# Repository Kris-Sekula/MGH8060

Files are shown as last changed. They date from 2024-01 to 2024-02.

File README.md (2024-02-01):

# MGH8060
SC/MP INS8060-based microcomputer running National Industrial Basic Language (NIBL)

Here is an overview of the device:

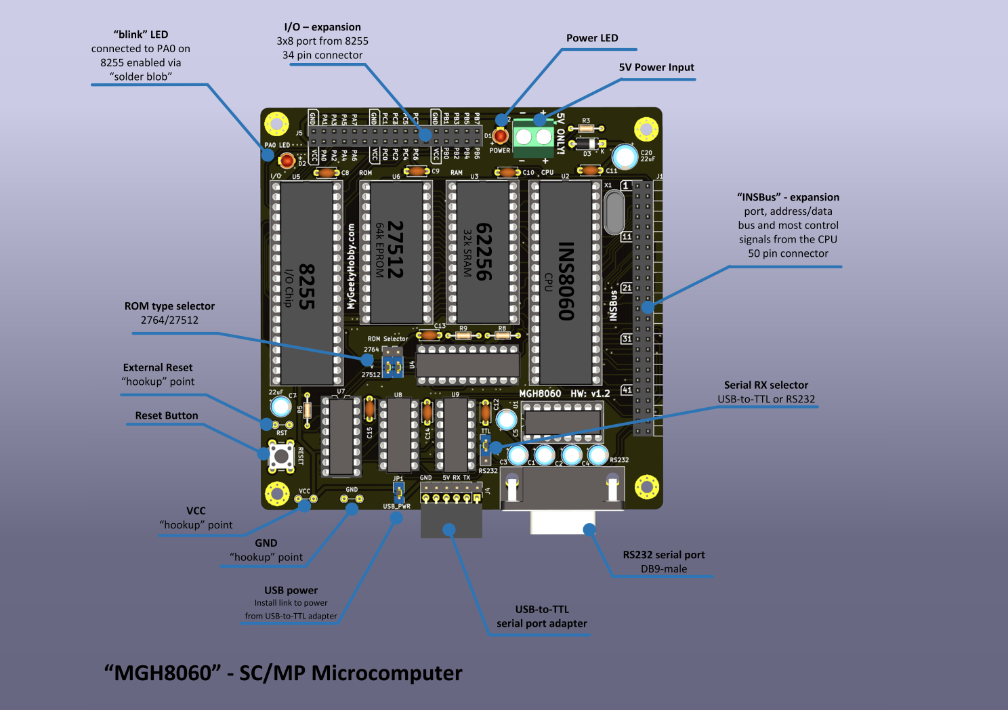
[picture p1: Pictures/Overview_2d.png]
MGH8060_overview


And here is my assembled unit - hardware v1.2

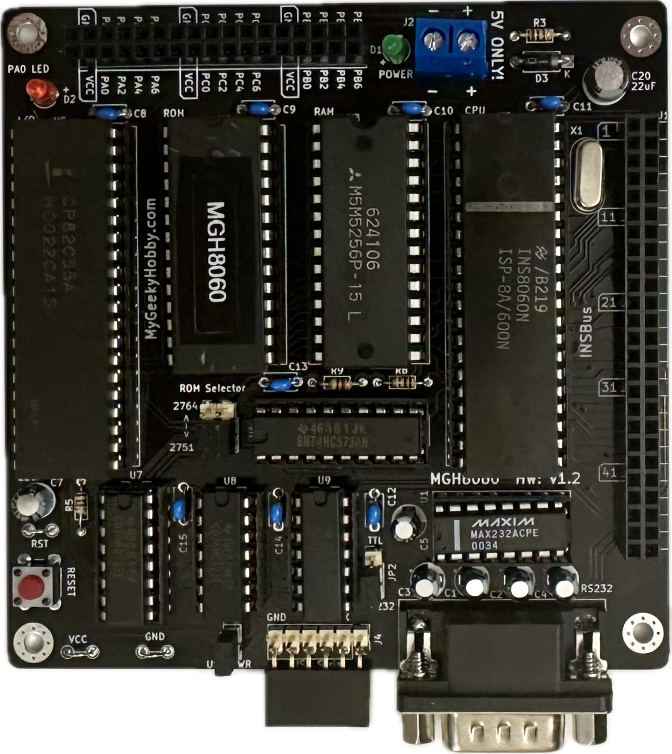
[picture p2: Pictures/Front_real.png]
Assembled_unit_v1.2


## Bill of Materials

| Component type | Reference | Description | Quantity |
| --- | --- | --- | --- |
| PCB | | [Order from PCBWay](https://www.pcbway.com/project/shareproject/MGH8060_SC_MP_Microcomputer_731c2144.html)| 1 |
| Integrated Circuit | U1 | MAX232(A) - RS232 Driver, 16 pin DIP | 1 | 
| Integrated Circuit | U2 | INS8060 - SC/MP II Microcontroller, 40 pin DIP | 1 |
| Integrated Circuit | U3 | HM62256B - 32kb SRAM, 28 pin DIP | 1 |
| Integrated Circuit | U4 | 74LS573 - high-speed octal latch, 20 pin DIP | 1 |
| Integrated Circuit | U5 | 8255A - Programmable Peripheral Interface, 40 pin DIP | 1 |
| Integrated Circuit | U6 | 27C512 - 64kb EPROM, 28 pin DIP | 1 |
| Integrated Circuit | U7 | 74LS138 - 3-to-8 line decoder, 16 pin DIP | 1 |
| Integrated Circuit | U8 | 74LS21 - Dual 4 -Input AND Logic, 14 pin DIP | 1 |
| Integrated Circuit | U8 | 74LS04 - HEX Inverter, 14 pin DIP | 1 |
| LED | D1 | LED indicator, 3 mm | 1 |
| LED | D2 | LED indicator, 3 mm | 1 |
| Diode | D3 | 1N4002,  general-purpose diode | 1 |
| Pin Header | J1 | 2x17 header female, 2.54 mm pitch | 1 |
| Connector | J2 | Screw terminal | 1 |
| Connector | J3 | DB9 male | 1 |
| Pin Header | J4 | 1x6 pin header, 2.54 mm pitch, angle | 1 |
| Pin Header | J5 | 2x25 header female, 2.54 mm pitch | 1 |
| Pin Header | J6 | 1x6 pin header, 2.54 mm pitch | 1 |
| Pin Header | JP1 | 1x2 pin header, 2.54 mm pitch | 1 |
| Pin Header | JP2-JP4 | 1x3 pin header, 2.54 mm pitch | 3 |
| Capacitor | C8-C15 | 1 uF, 16V, electrolytic, 2.54 mm pitch | 5 |
| Capacitor | C6 | 27pF, ceramic, 2.54 mm pitch | 1 |
| Capacitor | C8-C15 | 0.1 uF, 50V, MLCC, 5 mm pitch | 8 |
| Capacitor | C7,C20 | 22uF, 6.8V, electrolytic, 2.54 mm pitch | 2 |
| Resistor | R1 | 160 kohm, 0.125 W, axial | 1 |
| Resistor | R2-R4,R8 | 1 kohm, 0.125 W, axial | 4 |
| Resistor | R5 | 10k kohm, 0.125 W, axial | 1 |
| Resistor | R9 | 4.7k kohm, 0.125 W, axial | 1 |
| Crystal | X1 | 4MHz, short 3.5mm heigh max | 1 |
| IC Socket | U8,U9 | 14 pin DIP | 2 |
| IC Socket | U1,U7 | 16 pin DIP | 2 |
| IC Socket | U4 | 20 pin DIP | 1 |
| IC Socket | U3,U6 | 28 pin DIP | 2 |
| IC Socket | U2,U5 | 40 pin DIP | 2 |

## Memory Map

| Start | End | RAM | ROM | I/O |
| :---: | :---: | :----: | :----: | :----: |
| 0x0000 | 0x1FFF |  | X |  |			
| 0x2000 | 0x3FFF | X |  |  |			
| 0x4000 | 0x5FFF | X |  |  |			
| 0x6000 | 0x7FFF | X |  |  |			
| 0x8000 | 0x9FFF |  | X |  |			
| 0xA000 | 0xBFFF |  |  | X |			
| 0xC000 | 0xDFFF |  | X |  |			
| 0xE000 | 0xFFFF |  | X |  |

| Address | 8255 Function |
| :---: | :---: |
| 0xA000 | Port A |
| 0xA001 | Port B |
| 0xA002 | Port C |
| 0xA003 | Ctrl Register |

### Schematic
[Schematic - Version 1.2](Hardware/mgh8060_v1.2.pdf)

### Credits
* The device is based on the work of [Ronald Dekker](https://www.dos4ever.com/SCMP/SCMP.html#circuit)

* Early versions of my design were reviewed by Phil(aka [Retro Phil](https://www.mccrash-racing.co.uk/philg/picl/picl.htm)) who offered a lot of helpful suggestions, he also contributed all the firmware for MGH8060

## Release Notes

I used HCT parts for most of the ICs. Power usage was about 60mA

I used Winbond W27C512 (EEPROM pin compatible with EPROMs)

Please consider getting the PCB from my sponsor PCBWay

PCBWay (https://www.pcbway.com/project/shareproject/MGH8060_SC_MP_Microcomputer_731c2144.html)

If you found this helpful and you like the work I do, why not buy me a coffee, thanks! :)



### Changes
* Version 1.2:
  
  * Fixed missing connections. 

* Version 1.1:
  
  * Corrected CE signals (thanks Phil)

* Version 1.0
  
  * Initial version

## License

Copyright 2024 Kris Sekula

This work is licensed under a [Creative Commons Attribution-NonCommercial 4.0 International (CC BY-NC 4.0) ](https://creativecommons.org/licenses/by-nc/4.0/).

### Trademarks

* Other names and brands may be claimed as the property of others.

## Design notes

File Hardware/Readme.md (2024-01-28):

In the KiCad folder, you can find the KiCad sources for the PCB v1.2. 

## __Before you download the files, please consider ordering the PCBs from *PCBWay* by following this [-> link <-](https://www.pcbway.com/project/shareproject/MGH8060_SC_MP_Microcomputer_731c2144.html).__

I get a small portion of your order that I can use towards my future open-source projects, and more importantly, PCBWay will be more likely to sponsor me again.

Thanks again to PCBWay for sponsoring the PCBs used in this project.

PCBWay (https://www.pcbway.com/project/shareproject/MGH8060_SC_MP_Microcomputer_731c2144.html)

If you found this helpful and you like the work I do, why not buy me a coffee, thanks! :)



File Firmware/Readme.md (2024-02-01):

The main firmware file (mgh8060v2.hex) consists of 3 projects:

* National Industrial Basic Language (NIBL)
* NIBL with floating point extension
* Kitbug+ monitor

Connect to the device using one of the serial ports (RS232 or USB-to-TTL adapter), you should be using 2400 baud, 8-bit data, no parity, and one stop bit. The SC/MP is not fast enough to process at 2400 so you need to add a delay between characters and at the end of the line, here are my settings for the popular Tera Term program on Windows:

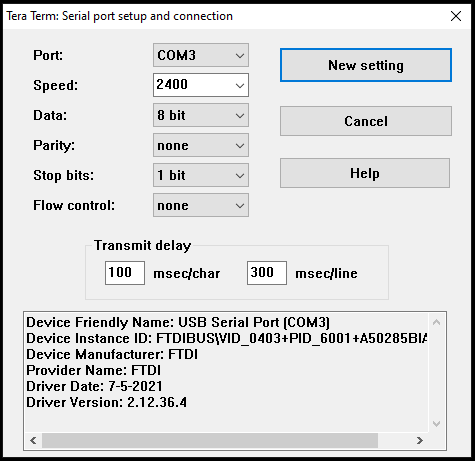
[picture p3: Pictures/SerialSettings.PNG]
SerialSettings


You may also want to adjust the "Terminal settings":

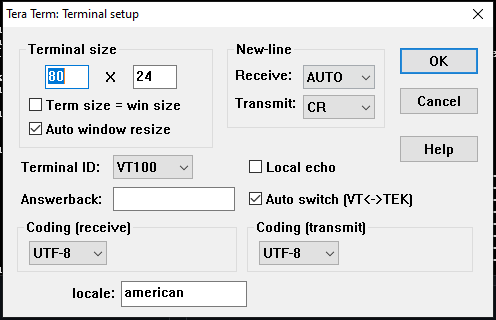
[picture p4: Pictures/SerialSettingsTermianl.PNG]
SerialSettingsTerminal


When you reset the board, a menu will be presented, select by pressing 1, 2 or 3:

Menu

There are also a few demo programs that can be uploaded via Kitbug+ "S" command and executed with the "G" command (filename indicates the upload and execution address)
| Filename | Description |
| :--: | :--: |
|fade_led_x6400.bin ||
|flash_led_x6000.bin ||
|life_x6800_jc.bin ||
|scmp_sine_0x6800.bin ||
|scmp_xmas2023_0x2800.bin ||
|xmasstar_x4800.bin ||

## Big thanks to "Retro Phil" who has been maintaining the Kitbug+ firmware and adapted it to the new memory mapping on this PCB, he has also created the "selection menu" for MGH8060... you can follow his adventures with SC/MP on his [page](https://www.mccrash-racing.co.uk/philg/picl/picl.htm).

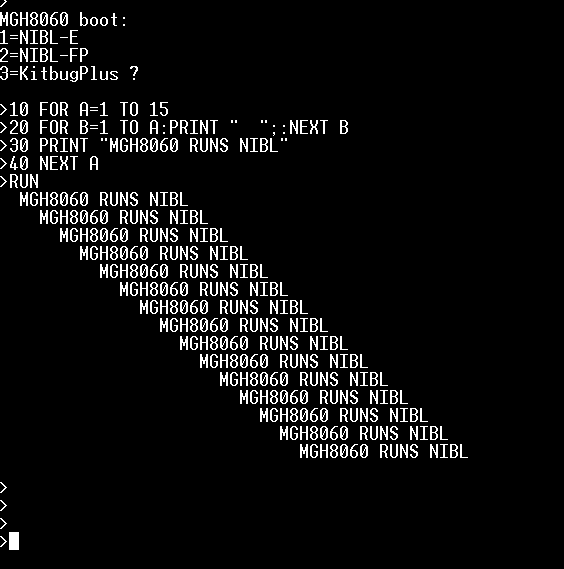
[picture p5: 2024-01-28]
Pictures/BOOTED.PNG

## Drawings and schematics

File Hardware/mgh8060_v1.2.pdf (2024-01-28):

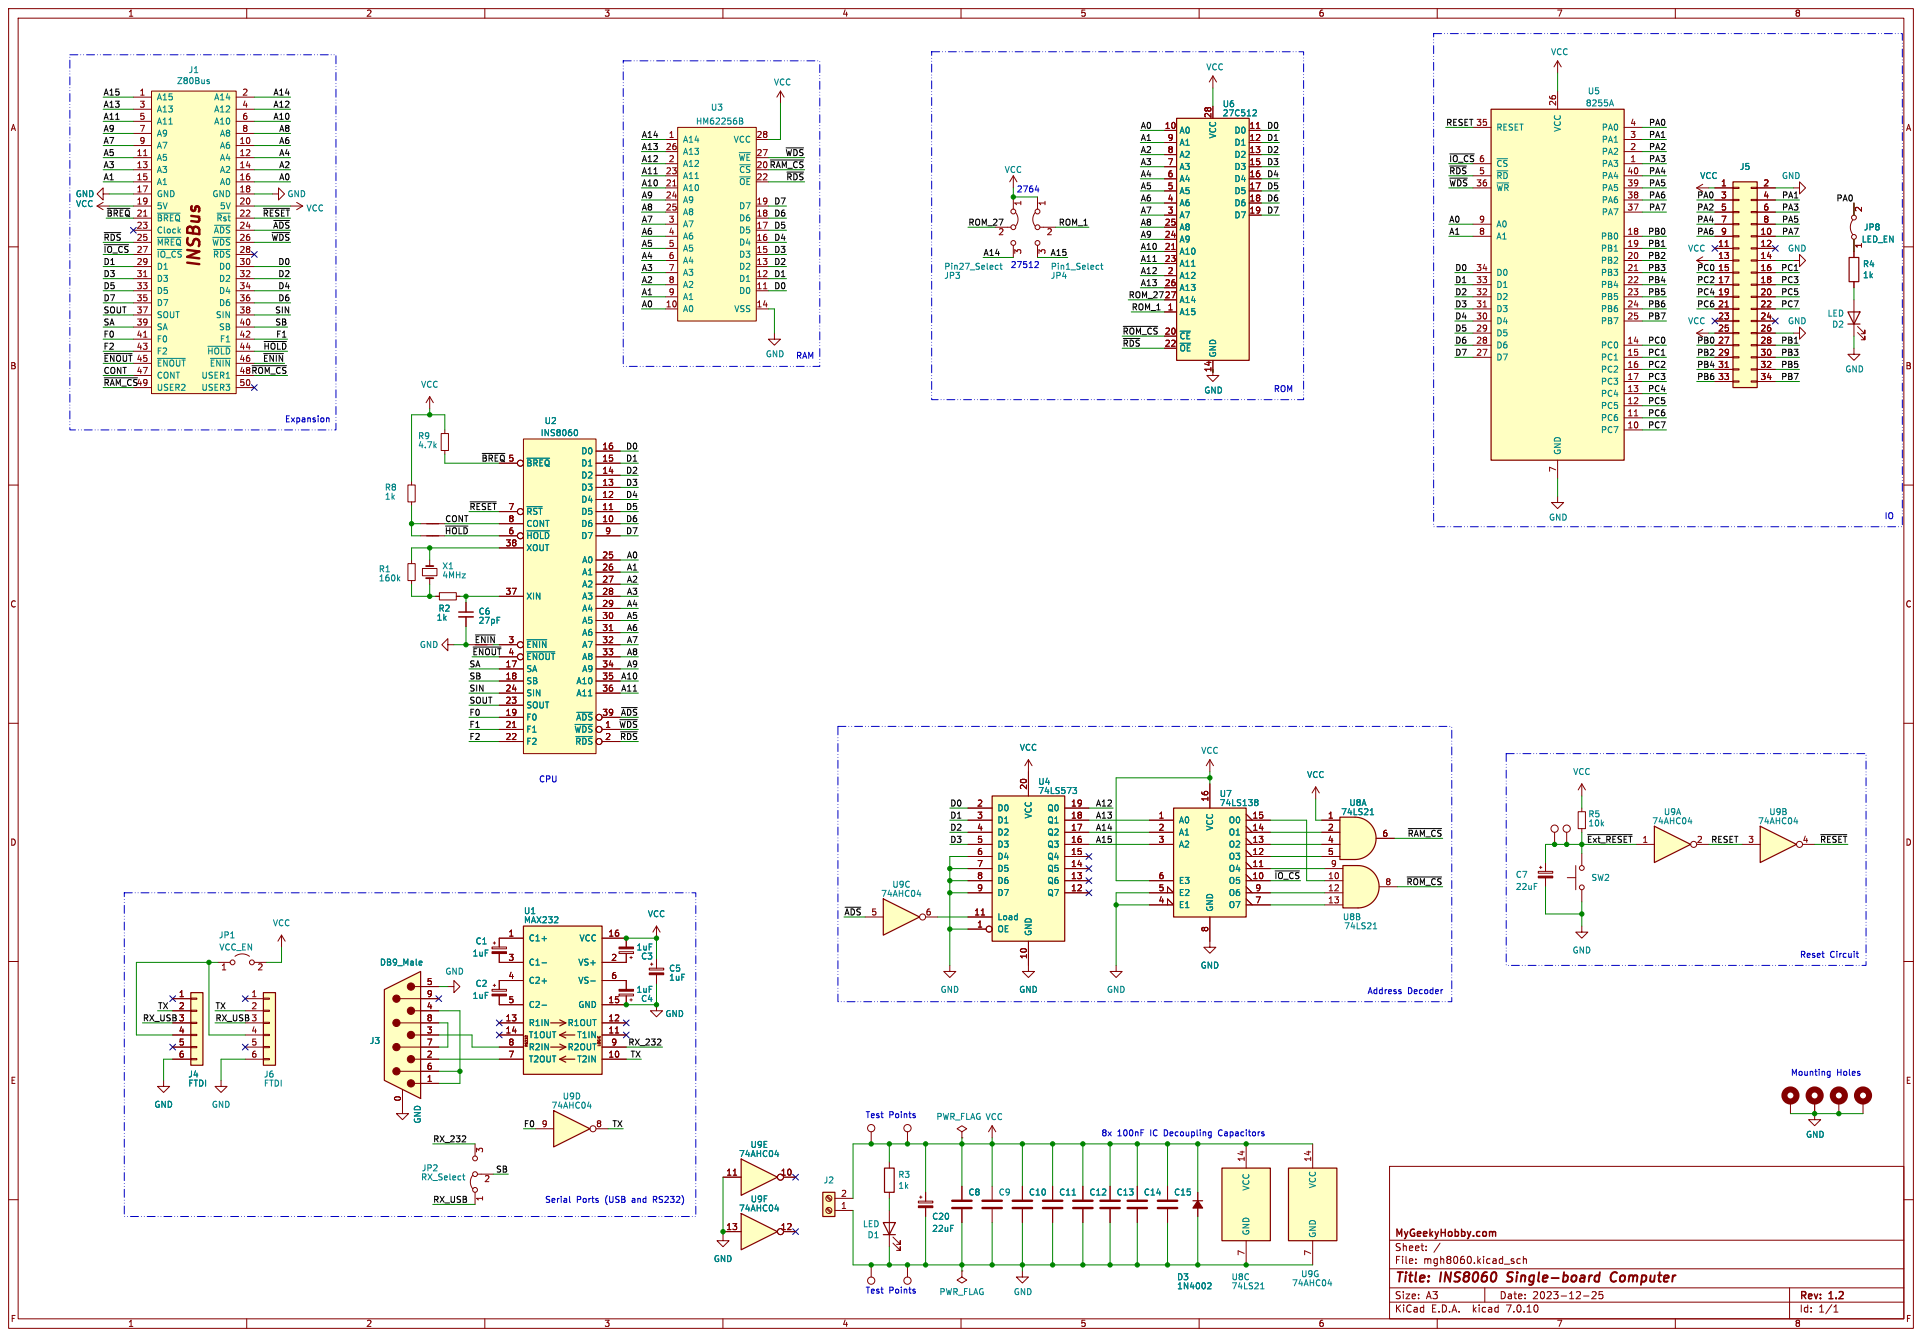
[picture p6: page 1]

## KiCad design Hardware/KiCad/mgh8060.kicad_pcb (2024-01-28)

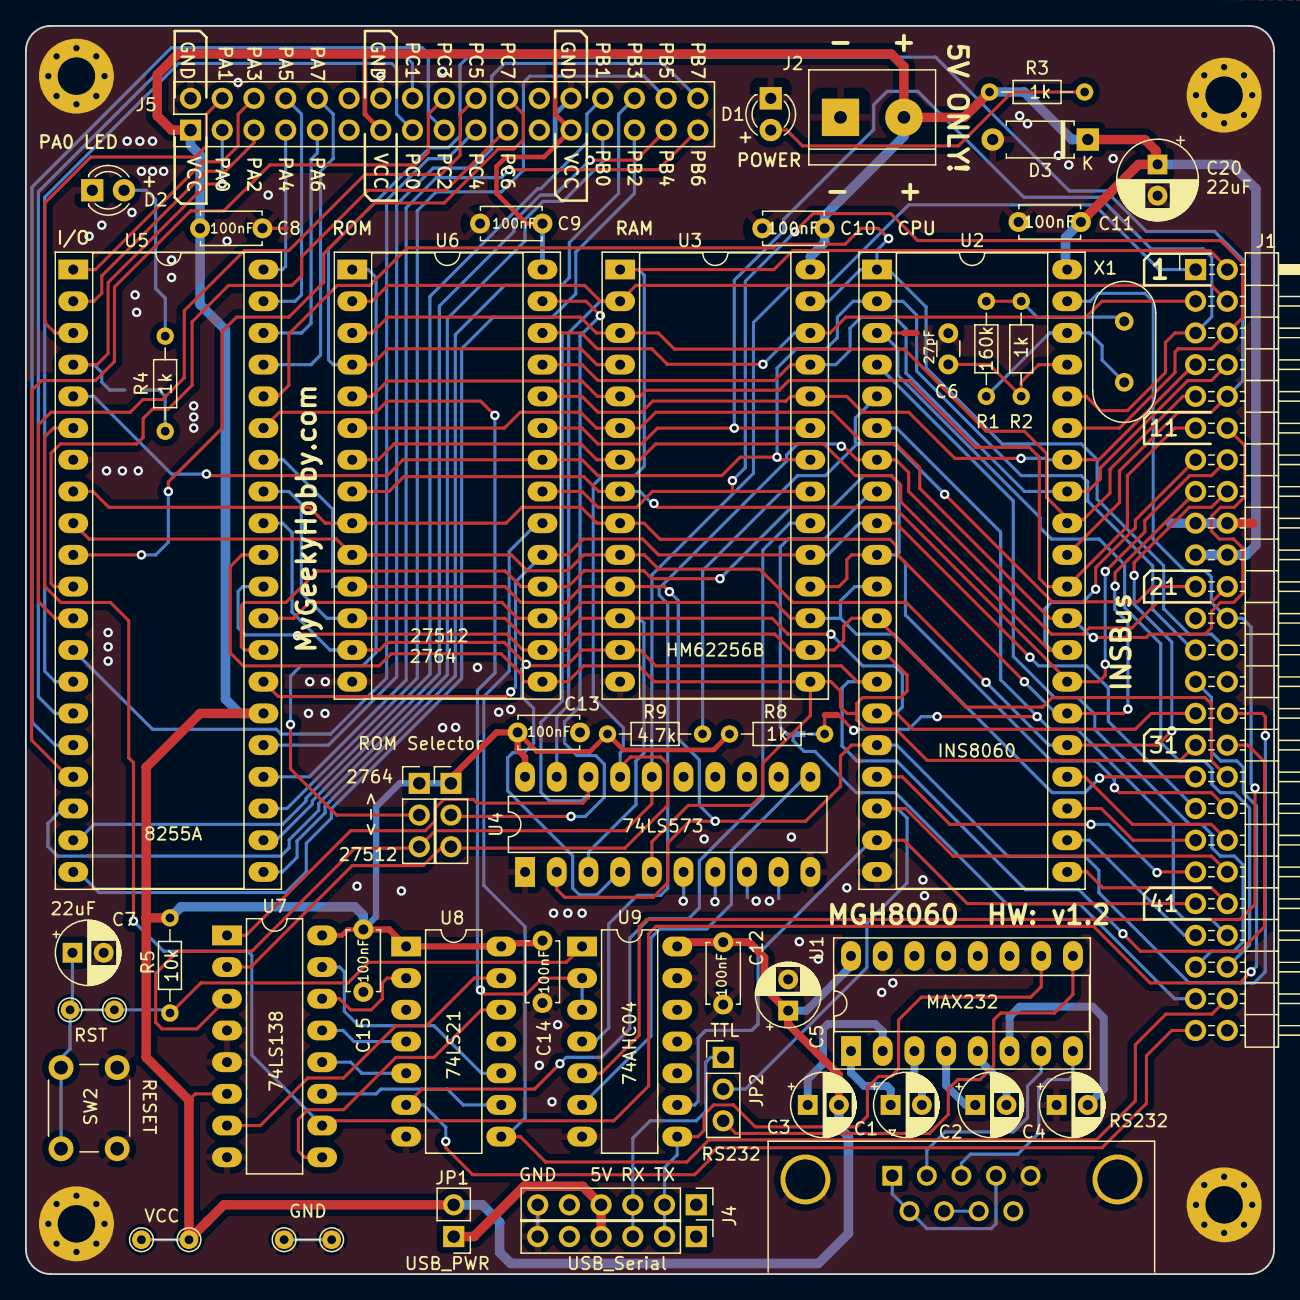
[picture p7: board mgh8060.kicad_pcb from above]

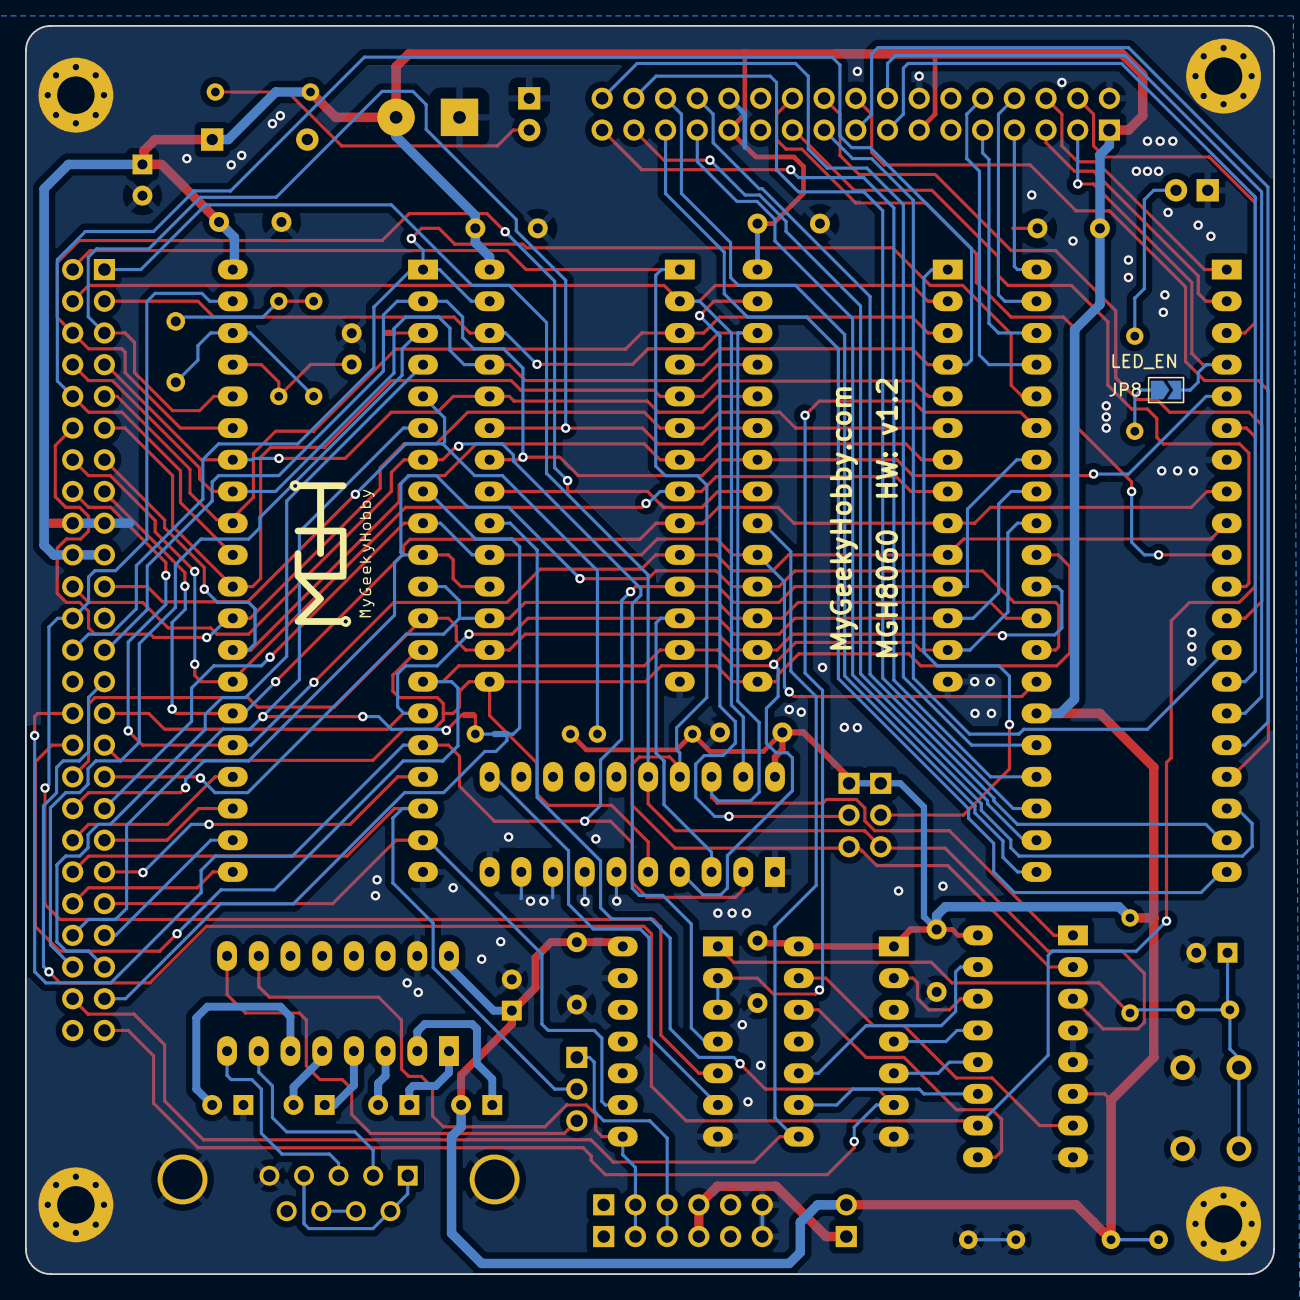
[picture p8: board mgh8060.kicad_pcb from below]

Board: 2 copper layers, 100.0 x 100.0 mm, 61 parts (2 on the bottom side), 102 nets.

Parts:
C1, C2, C3, C4, C5: 1uF; CP_Radial_D5.0mm_P2.50mm
C6: 27pF; C_Disc_D3.0mm_W1.6mm_P2.50mm
C7: 22uF; CP_Radial_D5.0mm_P2.50mm
C8, C9, C10, C11, C12, C13, C14, C15: 100nF; C_Disc_D4.7mm_W2.5mm_P5.00mm
C20: 22uF; CP_Radial_D6.3mm_P2.50mm
D1, D2: LED; LED_D3.0mm
D3: 1N4002; D_A-405_P7.62mm_Horizontal
H1, H2, H3, H4: MountingHole_Pad; MountingHole_3mm_Pad_Via
J1: Z80Bus; PinHeader_2x25_P2.54mm_Horizontal
J2: Screw_Terminal_01x02; TerminalBlock_bornier-2_P5.08mm
J3: DB9_Male; DSUB-9_Male_Horizontal_P2.77x2.84mm_EdgePinOffset4.94mm_Hou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
J4, J6: FTDI; PinHeader_1x06_P2.54mm_Vertical
J5: Conn_02x15_Odd_Even; PinHeader_2x17_P2.54mm_Vertical
JP1: VCC_EN; PinHeader_1x02_P2.54mm_Vertical
JP2: RX_Select; PinHeader_1x03_P2.54mm_Vertical
JP3: Pin27_Select; PinHeader_1x03_P2.54mm_Vertical
JP4: Pin1_Select; PinHeader_1x03_P2.54mm_Vertical
JP8: LED_EN; SolderJumper-2_P1.3mm_Open_TrianglePad1.0x1.5mm
NT1, NT2, NT3: NetTie_2; NetTie-2_SMD_Pad0.5mm
R1: 160k; R_Axial_DIN0204_L3.6mm_D1.6mm_P7.62mm_Horizontal
R2, R3, R4, R8: 1k; R_Axial_DIN0204_L3.6mm_D1.6mm_P7.62mm_Horizontal
R5: 10k; R_Axial_DIN0204_L3.6mm_D1.6mm_P7.62mm_Horizontal
R9: 4.7k; R_Axial_DIN0204_L3.6mm_D1.6mm_P7.62mm_Horizontal
SW2: SW_Push; SW_PUSH_6mm
TP1, TP3, TP7, TP8: 5V VCC; TestPoint_THTPad_D1.5mm_Drill0.7mm
TP2, TP4: GND; TestPoint_THTPad_D1.5mm_Drill0.7mm
U1: MAX232; DIP-16_W7.62mm_Socket_LongPads
U2: INS8060; DIP-40_W15.24mm_Socket_LongPads
U3: HM62256B; DIP-28_W15.24mm_Socket_LongPads
U4: 74LS573; DIP-20_W7.62mm_LongPads
U5: 8255A; DIP-40_W15.24mm_Socket_LongPads
U6: 27C512; DIP-28_W15.24mm_Socket_LongPads
U7: 74LS138; DIP-16_W7.62mm_LongPads
U8: 74LS21; DIP-14_W7.62mm_LongPads
U9: 74AHC04; DIP-14_W7.62mm_LongPads
X1: 4MHz; Crystal_HC49-U_Vertical

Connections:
/A0: J1.16 (A0), U2.25 (A0), U3.10 (A0), U5.9 (A0), U6.10 (A0)
/A1: J1.15 (A1), U2.26 (A1), U3.9 (A1), U5.8 (A1), U6.9 (A1)
/A2: J1.14 (A2), U2.27 (A2), U3.8 (A2), U6.8 (A2)
/A3: J1.13 (A3), U2.28 (A3), U3.7 (A3), U6.7 (A3)
/A4: J1.12 (A4), U2.29 (A4), U3.6 (A4), U6.6 (A4)
/A5: J1.11 (A5), U2.30 (A5), U3.5 (A5), U6.5 (A5)
/A6: J1.10 (A6), U2.31 (A6), U3.4 (A6), U6.4 (A6)
/A7: J1.9 (A7), U2.32 (A7), U3.3 (A7), U6.3 (A7)
/A8: J1.8 (A8), U2.33 (A8), U3.25 (A8), U6.25 (A8)
/A9: J1.7 (A9), U2.34 (A9), U3.24 (A9), U6.24 (A9)
/A10: J1.6 (A10), U2.35 (A10), U3.21 (A10), U6.21 (A10)
/A11: J1.5 (A11), U2.36 (A11), U3.23 (A11), U6.23 (A11)
/A12: J1.4 (A12), U3.2 (A12), U4.19 (Q0), U6.2 (A12)
/A13: J1.3 (A13), U3.26 (A13), U4.18 (Q1), U6.26 (A13), U7.1 (A0)
/A14: J1.2 (A14), JP3.3 (B), U3.1 (A14), U4.17 (Q2), U7.2 (A1)
/A15: J1.1 (A15), JP4.3 (B), U4.16 (Q3), U7.3 (A2)
/CONT: J1.47 (CONT), NT1.2, U2.8 (CONT)
/D0: J1.30 (D0), U2.16 (D0), U3.11 (D0), U4.2 (D0), U5.34 (D0), U6.11 (D0)
/D1: J1.29 (D1), U2.15 (D1), U3.12 (D1), U4.3 (D1), U5.33 (D1), U6.12 (D1)
/D2: J1.32 (D2), U2.14 (D2), U3.13 (D2), U4.4 (D2), U5.32 (D2), U6.13 (D2)
/D3: J1.31 (D3), U2.13 (D3), U3.15 (D3), U4.5 (D3), U5.31 (D3), U6.15 (D3)
/D4: J1.34 (D4), U2.12 (D4), U3.16 (D4), U5.30 (D4), U6.16 (D4)
/D5: J1.33 (D5), U2.11 (D5), U3.17 (D5), U5.29 (D5), U6.17 (D5)
/D6: J1.36 (D6), U2.10 (D6), U3.18 (D6), U5.28 (D6), U6.18 (D6)
/D7: J1.35 (D7), U2.9 (D7), U3.19 (D7), U5.27 (D7), U6.19 (D7)
/F0: J1.41 (F0), U2.19 (F0), U9.9
/F1: J1.42 (F1), U2.21 (F1)
/F2: J1.43 (F2), U2.22 (F2)
/PA0: J5.3, JP8.2 (B), U5.4 (PA0)
/PA1: J5.4, U5.3 (PA1)
/PA2: J5.5, U5.2 (PA2)
/PA3: J5.6, U5.1 (PA3)
/PA4: J5.7, U5.40 (PA4)
/PA5: J5.8, U5.39 (PA5)
/PA6: J5.9, U5.38 (PA6)
/PA7: J5.10, U5.37 (PA7)
/PB0: J5.27, U5.18 (PB0)
/PB1: J5.28, U5.19 (PB1)
/PB2: J5.29, U5.20 (PB2)
/PB3: J5.30, U5.21 (PB3)
/PB4: J5.31, U5.22 (PB4)
/PB5: J5.32, U5.23 (PB5)
/PB6: J5.33, U5.24 (PB6)
/PB7: J5.34, U5.25 (PB7)
/PC0: J5.15, U5.14 (PC0)
/PC1: J5.16, U5.15 (PC1)
/PC2: J5.17, U5.16 (PC2)
/PC3: J5.18, U5.17 (PC3)
/PC4: J5.19, U5.13 (PC4)
/PC5: J5.20, U5.12 (PC5)
/PC6: J5.21, U5.11 (PC6)
/PC7: J5.22, U5.10 (PC7)
/RESET: U5.35 (RESET), U9.2, U9.3
/ROM_1: JP4.2 (C), U6.1 (A15)
/ROM_27: JP3.2 (C), U6.27 (A14)
/RX_232: JP2.3 (B), U1.9 (R2OUT)
/RX_USB: J4.3, J6.3, JP2.1 (A)
/SA: J1.39 (SA), U2.17 (SA)
/SB: J1.40 (SB), JP2.2 (C), U2.18 (SB)
/SIN: J1.38 (SIN), U2.24 (SIN)
/SOUT: J1.37 (SOUT), U2.23 (SOUT)
/TX: J4.2, J6.2, U1.10 (T2IN), U9.8
/~ADS: J1.24 (~ADS), U2.39 (~ADS), U9.5
/~BREQ: J1.21 (~BREQ), R9.2, U2.5 (~BREQ)
/~ENIN: J1.46 (~ENIN), NT3.2, U2.3 (~ENIN)
/~ENOUT: J1.45 (~ENOUT), U2.4 (~ENOUT)
/~Ext_RESET: C7.1, R5.2, SW2.2, TP7.1, TP8.1, U9.1
/~HOLD: J1.44 (~HOLD), NT2.2, U2.6 (~HOLD)
/~IO_CS: J1.27 (~IO_CS), U5.6 (~CS), U7.10 (O5)
/~RAM_CS: J1.49 (USER2), U3.20 (~CS), U8.6
/~RDS: J1.25 (~MREQ), U2.2 (~RDS), U3.22 (~OE), U5.5 (~RD), U6.22 (~OE)
/~RESET: J1.22 (~Rst), U2.7 (~RST), U9.4
/~ROM_CS: J1.48 (USER1), U6.20 (~CE), U8.8
/~WDS: J1.26 (~WDS), U2.1 (~WDS), U3.27 (~WE), U5.36 (~WR)
GND: C4.1, C5.2, C6.2, C7.2, C8.2, C9.2, C10.2, C11.2, C12.2, C13.2, C14.2, C15.2, C20.2, D1.1 (K), D2.1 (K), D3.2 (A), H1.1, H2.1, H3.1, H4.1, J1.17 (GND), J1.18 (GND), J2.1, J3.0 (PAD), J3.5, J4.6, J5.2, J5.14, J5.26, J6.6, NT3.1, SW2.1, TP2.1, TP4.1, U1.15 (GND), U2.20 (GND), U3.14 (VSS), U4.1 (OE), U4.6 (D4), U4.7 (D5), U4.8 (D6), U4.9 (D7), U4.10 (GND), U5.7 (GND), U6.14 (GND), U7.4 (E1), U7.5 (E2), U7.8 (GND), U8.7 (GND), U9.7 (GND), U9.11, U9.13
unnamed: D1.2 (A), R3.2
unnamed: D2.2 (A), R4.2
unnamed: J3.1, J3.4, J3.6
unnamed: J3.7, J3.8
unnamed: J4.4, J6.4, JP1.1 (A)
unnamed: JP8.1 (A), R4.1
unnamed: NT1.1, NT2.1, R8.2
unnamed: R1.2, R2.1, X1.1
unnamed: C1.1, U1.1 (C1+)
unnamed: C1.2, U1.3 (C1-)
unnamed: C2.1, U1.4 (C2+)
unnamed: C2.2, U1.5 (C2-)
unnamed: J3.3, U1.8 (R2IN)
unnamed: J3.2, U1.7 (T2OUT)
unnamed: C3.1, U1.2 (VS+)
unnamed: C4.2, U1.6 (VS-)
unnamed: C6.1, R2.2, U2.37 (XIN)
unnamed: R1.1, U2.38 (XOUT), X1.2
unnamed: U4.11 (Load), U9.6
unnamed: U7.15 (O0), U8.10
unnamed: U7.14 (O1), U8.2
unnamed: U7.13 (O2), U8.4
unnamed: U7.12 (O3), U8.5
unnamed: U7.11 (O4), U8.9
unnamed: U7.9 (O6), U8.12
unnamed: U7.7 (O7), U8.13
VCC: C3.2, C5.1, C8.1, C9.1, C10.1, C11.1, C12.1, C13.1, C14.1, C15.1, C20.1, D3.1 (K), J1.19 (5V), J1.20 (5V), J2.2, J5.1, J5.13, J5.25, JP1.2 (B), JP3.1 (A), JP4.1 (A), R3.1, R5.1, R8.1, R9.1, TP1.1, TP3.1, U1.16 (VCC), U2.40 (VCC), U3.28 (VCC), U4.20 (VCC), U5.26 (VCC), U6.28 (VCC), U7.6 (E3), U7.16 (VCC), U8.1, U8.14 (VCC), U9.14 (VCC)

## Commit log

2024-01-28 Update README.md
    Added BOM
2024-01-28 Added PCB files
    [mgh8060.kicad_pcb]
